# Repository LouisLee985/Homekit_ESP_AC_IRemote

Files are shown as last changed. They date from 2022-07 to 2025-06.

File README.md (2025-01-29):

# Homekit_ESP_AC_IRemote


<p align="center">

</p>

<p align="center">

</p>
<br>

### [WiFiManager](https://github.com/tzapu/WiFiManager?tab=readme-ov-file#how-it-works)
* When your ESP starts up, it sets it up in Station mode and tries to connect to a previously saved Access Point
* if this is unsuccessful (or no previous network saved) it moves the ESP into Access Point mode and spins up a DNS and WebServer (default ip 192.168.4.1)
* using any wifi enabled device with a browser (computer, phone, tablet) connect to the newly created Access Point
* because of the Captive Portal and the DNS server you will either get a 'Join to network' type of popup or get any domain you try to access redirected to the configuration portal
* choose one of the access points scanned, enter password, click save
* ESP will try to connect. If successful, it relinquishes control back to your app. If not, reconnect to AP and reconfigure.
* There are options to change this behavior or manually start the configportal and webportal independantly as well as run them in non blocking mode.
<br>

### HomeKit setup
In your iOS device, open Home App and follow normal steps to [add a new accessory](https://support.apple.com/en-us/104998).

* Homekit Normal Code:
  ```
  985-21-985
  ```

* Homekit QR-Code:
<div align="center">
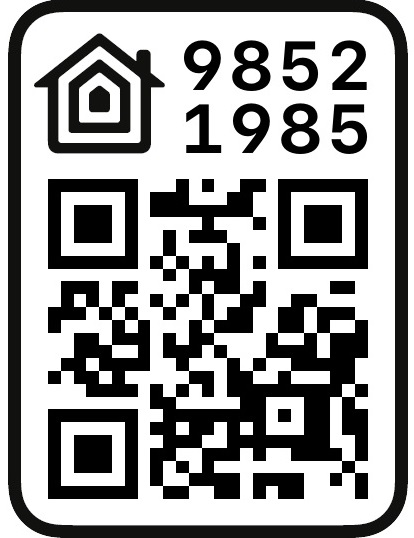
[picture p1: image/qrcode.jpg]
<br>
</div>  　

<br>

   ### Air Conditioning Features

1. Apple HomeKit App Air Conditioning Features: Power on, Power off, Cooling, Heating, ~~Fan speed~~， Current ambient temperature and humidity display. 
<br>Based on [HomeKit Accessory Protocol Specification(Noncommercial Version) Release R2](https://developers.apple.com/homekit/faq)  ，there is a disclaimer stating that *`This accessory has not been certified for use with HomeKit, therefore some features may not be available.`* .
2. If you need to remotely control HomeKit accessories while away from home, please [Set up your HomePod, HomePod mini, Apple TV, or iPad as a home hub](https://support.apple.com/en-us/102557)
3. Infrared Signal Feedback: When a standard air conditioner remote performs actions supported by the Apple HomeKit protocol such as power on, power off, cooling, heating, and ~~fan speed~~, the HomeKit App will synchronously update the status.

<div align="center">
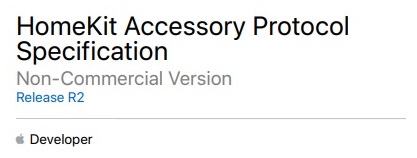
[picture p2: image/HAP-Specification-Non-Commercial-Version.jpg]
<br>
</div>
<br>

### Button IO0

  - Long pressed&ensp;&ensp;5-10 second:&emsp;Set up the infrared protocol.
  - Long pressed&ensp;10-15 second:&emsp;Restore settings.
<br>

# Thanks
* [HomeKit Accessory Protocol Specification(Noncommercial Version) Release R2](https://developers.apple.com/homekit/faq)
* [arduino-sht](https://github.com/Sensirion/arduino-sht) 
* [WiFiManager](https://github.com/tzapu/WiFiManager)
* [IRremoteESP8266](https://github.com/crankyoldgit/IRremoteESP8266) 
* [Arduino-HomeKit-ESP8266](https://github.com/Mixiaoxiao/Arduino-HomeKit-ESP8266) 
* [arduino-button-long-press-short-press](https://arduinogetstarted.com/tutorials/arduino-button-long-press-short-press)
*  https://github.com/openscopeproject/InteractiveHtmlBom

<div align="center">  
 
</div>

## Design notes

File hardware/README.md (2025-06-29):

# AC_IRemote_ESP-01F
* <a href='http://htmlpreview.github.io/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'>InteractiveHtmlBom</a>

<div align="center">
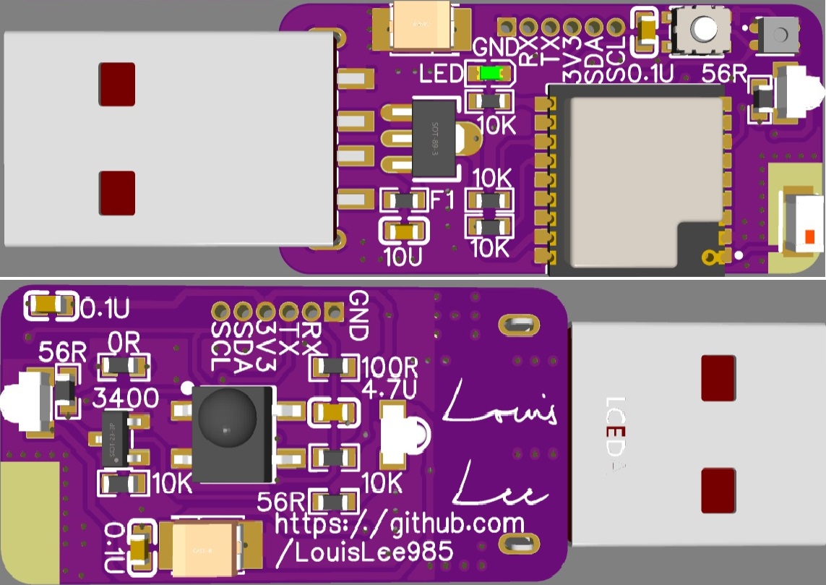
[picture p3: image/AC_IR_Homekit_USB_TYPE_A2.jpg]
AC_IR_Homekit_USB_TYPE_A2
<br>
<br>
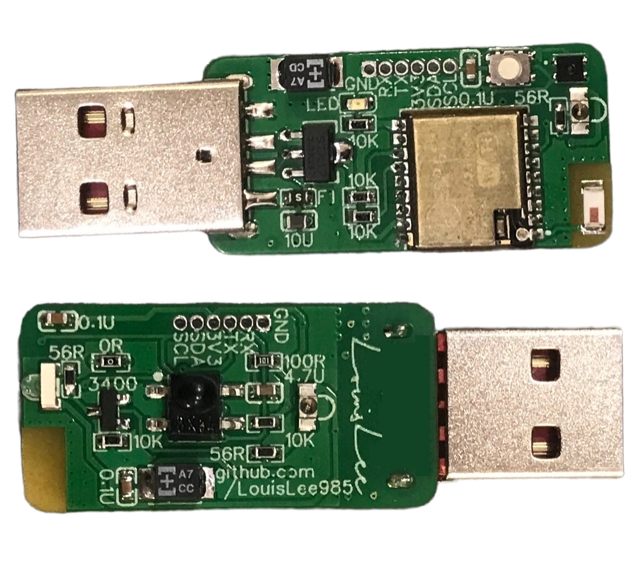
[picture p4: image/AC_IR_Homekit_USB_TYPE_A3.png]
AC_IR_Homekit_USB_TYPE_A3
<br>
<br> 
<br>
<br>
</div>
<br>

* Regarding Temperature and Humidity:
<br>Due to the compactness of the PCB, the temperature and humidity sensor *`SHTC3`*  on the PCB is affected by the heat dissipation of the *`ESP-01F`*  ,resulting in consistently higher temperature readings.
<br>The temperature and humidity sensor and related resistors and capacitors U8,R8,R9,C5，can be left unsoldered, and the temperature and humidity display in the HomeKit App will show 0.

* If accurate temperature and humidity readings are required, do not solder U8,R8,R9,C5， After flashing the firmware, connect an external *`temperature and humidity sensor module`* , keeping it away from heat sources.
<br>SDA,SCL,3V3,GNDare used for connecting an external *`temperature and humidity sensor module`*.
<br>水合：饱和盐水，20-30度，湿度>=70%,密闭小空间>=12小时。

* Supported external SHT *`temperature and humidity sensor modules`*: 　SHTC1，SHTC3，SHTW1，SHTW2，SHT3x-DIS (I2C)，SHT3x-ARP (ratiometric analog voltage output)，SHT85，SHT4x，e.g.
<div align="center">
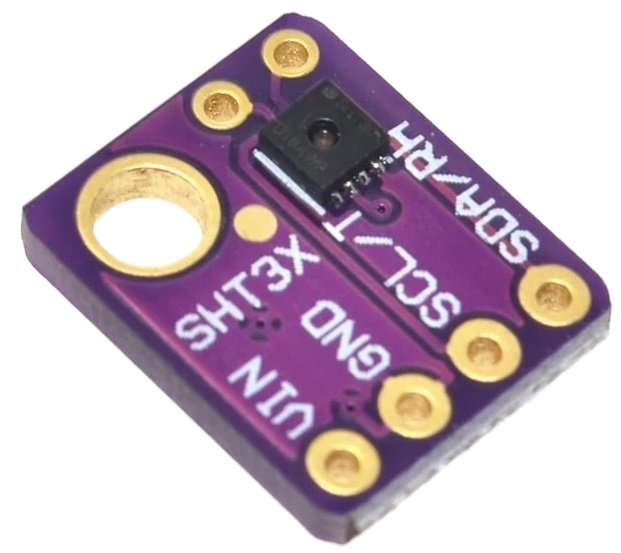
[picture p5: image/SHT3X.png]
<br>
 </div> 

* AC_IRemote_ESP-01F PIN

<div align = "center">

| IR_T(OUT) |IO14|
| :---: |:---: |
|**IR_R(IN)** |**IO12**|
|**LED** |**IO2**|
|**Button**|**IO0** |
|**SDA**|**IO4** |
|**SCL**|**IO5** |
</div>

## [Sparkfun_ir_blaster ](https://github.com/sparkfun/ESP8266_WiFi_IR_Blaster)
* SparkFun WiFi IR Blaster (ESP8266) is supported. 
&emsp;&emsp;
[sparkfun_ir_blaster.bin](https://github.com/LouisLee985/Homekit_ESP_AC_IRemote/releases/download/v1.2.0/Air_Conditioner_Remote_1.2.0-sparkfun_ir_blaster.bin)

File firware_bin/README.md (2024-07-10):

# Homekit_ESP_AC_IRemote

### Installation
<ol>
<li>Connect your device to your FTDI adapter in flash-mode, holding down device button IO0 while connecting or connecting GPIO-0 to GND.
</li>
<li>Use  <a href="https://www.espressif.com.cn/zh-hans/support/download/other-tools">flash_download_tool</a> to flash it in your device.</li>

<br>Homekit_AC_Remote_1.0.0.bin，@0x0
<br>DoNotChgBin is unchecked。
<br>select COM：...，BAUD:115200。
<br>ERASE...
<br>START...
</ol>

<div align="center">
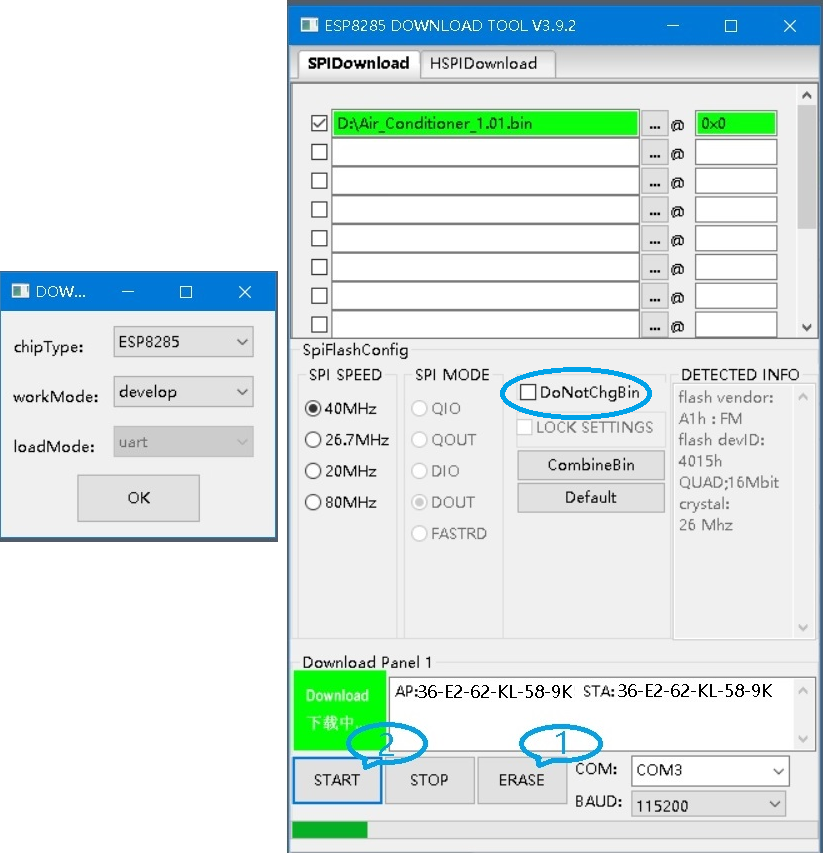
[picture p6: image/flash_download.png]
flash_download
<br>
</div>

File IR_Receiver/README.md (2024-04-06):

## IR receiver Pin  GPIO 12

* Flash to 0x0 of device based on an ESP8266 microcontroller (ESP8266EX and ESP8285 chips), rboot.bin and blank_config.bin is not needed.
* Power off device.
* Connect receiver data pin to GPIO 12 using an IR receiver like <a href="https://www.cytron.io/p-ir-receiver-diode-vs1838b-38khz">VS1838B</a>, <a href="https://www.vishay.com/en/product/82484/">TSMP1138</a> ...
* Power on device using USB adapter.
* Output is transmitted to UART. You can read it using screen command or any other serial reader.
* To get a good capture, put IR transmitter very near of receiver (1cm - 0.4inch).

---
## Data format

* The haa_ir_capture.bin is compiled from <a href="https://github.com/RavenSystem/esp-homekit-devices/releases/tag/HAAIR_1.0.0">HAA IR Capture Tool v1.0</a></h3>

```
Packets: 199
Standard Format
+ 4323 - 4515 +  494 - 1690 +  493 -  585 ... ... ...
HAA RAW Format
JhJkAODFAOAhAODFAODFAOAhATAcATDAATAcATAcATDAATAcATAcATDAATDAATAcATDAATDAATDAATDAATDAATDAATDAATDAATDAATAcATAcATAcATAcATAcATAcATAcATAcATDAATAcATAcATDAATDAATDAATAcATAiANAcATDAATDAATAcATAcATAcATDAATDAATL1JoJ#ATDAASAdASDAATDAATAcATAcASDAATAcATAcASDAATAcASAdASDBASDBASAdASDBASDAASDBASDBASDBASDBASDBASDBASDBASAdASAdASAdASAdASAdASAdASAdASAdASDBARAdASAdASDBARDCARDBARAeARAeARAeARDCARDCARAeARAeARAeARDCARDCAR
```

* IRrecvDumpV2.bin is compiled from <a href="https://github.com/crankyoldgit/IRremoteESP8266">IRremoteESP8266</a>

```
Timestamp : 000470.742,  Library : v2.8.2
Code : 0xA1834AFFFF56 (48 Bits)
Protocol: 34 (MIDEA), Type: 1 (Command), Power: On, Mode: 3 (Heat), Celsius: On, Temp: 27C/80F, On Timer: Off, Off Timer: Off, Fan: 0 (Auto), Sleep: Off, Swing(V): -, Econo: -, Turbo: -, Quiet: Off, Light: -, Clean: -, 8C Heat: -
uint16_t rawData[199] = {4444, 4560,  536, 1714,  538, 618,  ... ... ... };  // MIDEA A1834AFFFF56
uint64_t data = 0xA1834AFFFF56;
```

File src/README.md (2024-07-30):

* 部分代码，部分功能: 制冷，温湿度。如要使用，修改wifi_info.h line13,14中wifi的 ssid password后编译。
* [releases](https://github.com/LouisLee985/Homekit_ESP_AC_IRemote/releases) 实现更多功能。

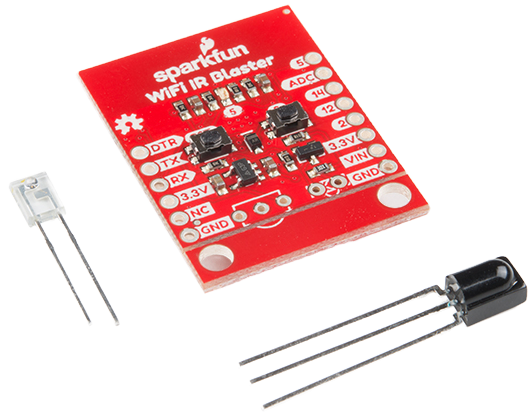
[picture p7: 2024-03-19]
image/SparkFun_WiFi_IR_Blaster_ESP8266.png

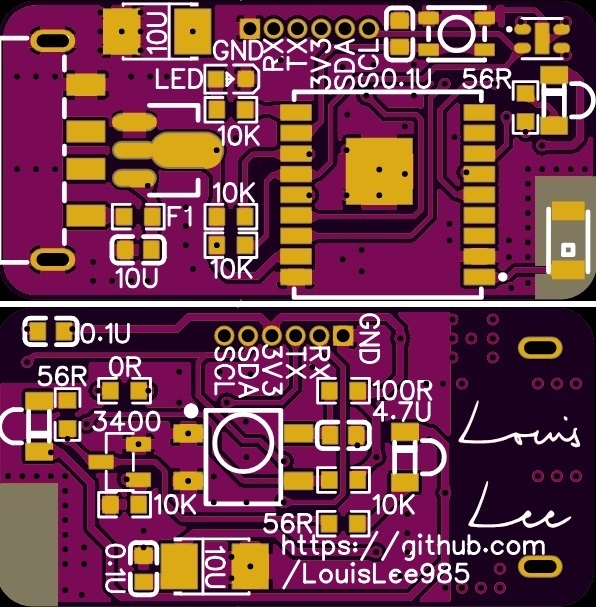
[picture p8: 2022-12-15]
image/AC_IR_Homekit_USB_TYPE_A1.jpg

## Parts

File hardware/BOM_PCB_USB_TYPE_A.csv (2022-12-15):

ID | Name | Designator | Footprint | Quantity | Manufacturer Part | Manufacturer | Supplier | Supplier Part | link
1 | 0R | R6 | R0603 | 1 | ERJ3GEY0R00V | PANASONIC(松下) | LCSC | C122704 | https://www.mouser.in/datasheet/2/447/PYu_RT_1_to_0_01_RoHS_L_11-1669912.pdf
2 | 10U | C1,C8 | CAP-SMD_L3.5-W2.8-R-RD | 2 | 16TQC10M | PANASONIC | LCSC | C147769 | https://atta.szlcsc.com/upload/public/pdf/source/20160107/1457707745471.pdf
3 | 0.1U | C2,C5,C3 | C0603 | 3 | CGA3E2X7R1E104KT0Y0N | TDK | LCSC | C338117 | https://item.szlcsc.com/362304.html
4 | 4.7U | C6 | C0603 | 1 | C1608X5R1C475KTK00E | TDK | LCSC | C342985 | https://item.szlcsc.com/362304.html
5 | IR_R | CGQ1 | SENSOR-SMD_IRM-H638T-TR2-TL | 1 | IRM-H638T/TR2 | EVERLIGHT | LCSC | C91447 | https://item.szlcsc.com/92636.html
6 | 3400 | Q1 | SOT-23-3_L2.9-W1.3-P1.90-LS2.4-BR | 1 | AO3400A | HUASHUO(华朔) | LCSC | C700953 | https://www.diodes.com/assets/Package-Files/SOT23.pdf
7 | 10K | R1,R10,R2,R8,R9 | R0603 | 5 | ERJU3RD1002V | PANASONIC | LCSC | C491175 | https://www.mouser.in/datasheet/2/447/PYu_RT_1_to_0_01_RoHS_L_11-1669912.pdf
8 | 56R | R4,R5,R3 | R0603 | 3 | ERJ3RED56R0V | PANASONIC | LCSC | C416765 | https://www.mouser.in/datasheet/2/447/PYu_RT_1_to_0_01_RoHS_L_11-1669912.pdf
9 | 100R | R13 | R0603 | 1 | ERA3AEB101V | PANASONIC | LCSC | C445624 | https://www.mouser.in/datasheet/2/447/PYu_RT_1_to_0_01_RoHS_L_11-1669912.pdf
10 | IR_T | U4,U5,U3 | LED-SMD_L3.0-W2.7-RD | 3 | IR26-61C/L302/TR8 | EVERLIGHT | LCSC | C181893 | https://atta.szlcsc.com/upload/public/pdf/source/20180207/C181893_15179899213401356555.pdf
11 | ESP-01F-2M-LL | L1 | WIFIM-SMD_ESP-01F-2M-LL | 1 | ESP-01F-2M | Ai-Thinker(安信可) | LCSC | C2764054 | https://item.szlcsc.com/2895541.html
12 | K2-1849SN-A3DW-06_LL | SW2 | SW-SMD_4P-L3.0-W2.8-P1.7-LS3.5 | 1 | K2-1849SN-A3DW-06 | Korean Hroparts Elec | LCSC | C442593 | https://atta.szlcsc.com/upload/public/pdf/source/20191030/C442593_F2569C1D94F849BB65E2EF23C54A3D8B.pdf
13 | 2450AT18A100E | AE1 | ANT-SMD_L3.2-W1.6 | 1 | 2450AT18A100E | Johanson Dielectrics | LCSC | C89334 | https://item.szlcsc.com/97946.html
14 | 10U | C9 | C0603 | 1 | C1608X6S1A106MT000E | TDK | LCSC | C342875 | https://item.szlcsc.com/362304.html
15 | 0603L100SLYR | F1 | R0603 | 1 | 0603L100SLYR | Littelfuse | LCSC | C207017 | https://www.mouser.in/datasheet/2/447/PYu_RT_1_to_0_01_RoHS_L_11-1669912.pdf
16 | 19-21/R6C-FP1Q2L/3T | LED | LED0603-RD | 1 | 19-21/R6C-FP1Q2L/3T | EVERLIGHT | LCSC | C93128 | https://item.szlcsc.com/347874.html
17 | AMS1117 | U2 | SOT-89_L4.5-W2.5-P1.50-LS4.2-BR-WXC | 1 | AMS1117-3.3 | Youtai Semiconductor Co., Ltd. | LCSC | C347256
18 | SHTC3 | U8 | SENSORM-SMD_4P-L2.0-W2.0-P1.00 | 1 | SHTC3 | Sensirion | LCSC | C194656 | https://item.szlcsc.com/237872.html
19 | U-G-08WS-W-01 | USB2 | USB-A-SMD_U-G-08WS-W-01 | 1 | U-G-08WS-W-01 | 韩国韩荣 | LCSC | C840351 | https://atta.szlcsc.com/upload/public/pdf/source/20200918/C840351_DD82F555CFE8A4EC814B17A8169E3B99.pdf

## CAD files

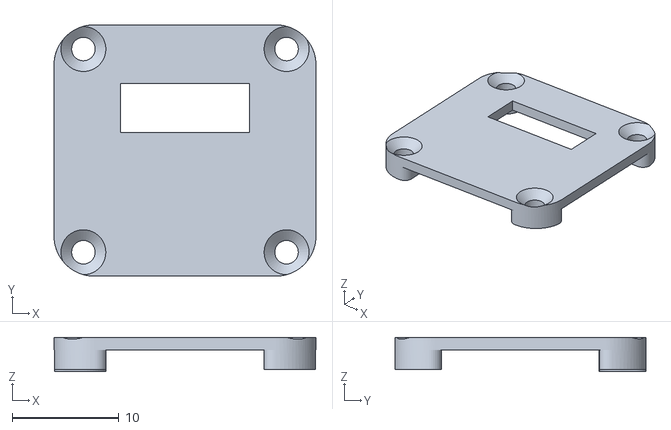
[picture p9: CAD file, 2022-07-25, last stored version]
hardware/AC_IR_Homekit_5V1A_3.0_0402/BASE_15.stl
24.5 x 23.5 x 3.20

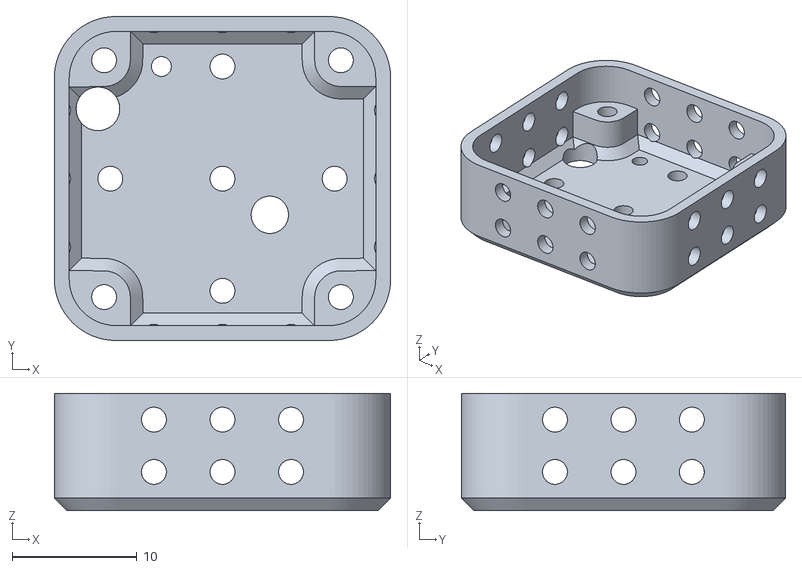
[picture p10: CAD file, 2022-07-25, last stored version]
hardware/AC_IR_Homekit_5V1A_3.0_0402/COVER.stl
27.0 x 26.0 x 9.40

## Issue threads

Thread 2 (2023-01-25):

日立空調能用嗎? RAS-28NK

shengweitw, 2023-01-25:
請問這類空調是否可用?   遙控器型號: RS11T3

shengweitw, 2023-01-25:
請問一下，你的MCU接腳定義與https://github.com/Mixiaoxiao/ESP8266-IR-HOMEKIT相同嗎?

shengweitw, 2023-01-25:
https://github.com/Mixiaoxiao/ESP8266-IR-HOMEKIT

LouisLee985, 2023-01-25:
Yes,but no IO13.

shengweitw, 2023-01-25:
我的遙控器配對，無效，但在上一個版本我可以用RF11T1 remote (HITACHI_AC344)這個設定來控制。這邊該如何設定它使用RF11T1 remote (HITACHI_AC344)這個設定?

LouisLee985, 2023-01-25:
IO0 按钮(IO0接GND) 5秒，遥控器对码。

Closed 2023-07-02.

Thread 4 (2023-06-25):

SparkFun WiFi IR Blaster (ESP8266)

iondarie, 2023-06-25:
Hello,

Is there any way i could get this working on a SparkFun WiFi IR Blaster (ESP8266) board?

IR_LED_RECEIVE = 13
IR_LED_SEND = 4

Thank you,

LouisLee985, 2023-06-30:
IR_SEND_PIN                   14
IR_RECEIVE_PIN                   12

LouisLee985, 2023-06-30:
IR_SEND_PIN =14
IR_RECEIVE_PIN =12

LouisLee985, 2023-07-01:
[ESP8266_WiFi_IR_Blaster](https://github.com/sparkfun/ESP8266_WiFi_IR_Blaster)

iondarie, 2023-07-01:
Thank you!!! I will try asap and come back with the results

iondarie, 2023-07-03:
"Unable to Add Accessory. Accessory is out of compliance"

this is the log if it helps:

```
[20:17:33]>>> [  64541] HomeKit: Got new client: local 192.168.1.96:5556, remote 192.168.1.121:58505
[20:17:33]>>> [  64550] HomeKit: [Client 1073699956] Pair Setup Step 1/3
[20:17:33]>>> [  64632] HomeKit: [Client 1073699956] Pair Setup Step 2/3
[20:17:33]>>> [  64643] HomeKit: Call s_mp_exptmod in integer.c, original winsize 6
[20:17:43]>>> [  74672] HomeKit: Call s_mp_exptmod in integer.c, original winsize 5
[20:17:49]>>> [  79808] HomeKit: [Client 1073699956] Pair Setup Step 3/3
[20:17:49]>>> [  79837] HomeKit: Call ge_double_scalarmult_vartime_lowmem in ge_low_mem.c
[20:17:49]>>> [  80558] HomeKit: Added pairing with 81429B0D-497F-4A9B-BDDB-D96D195999B8
[20:17:49]>>> [  80631] HomeKit: Free saved_preinit_pairing_context
[20:17:49]>>> [  80636] HomeKit: [Client 1073699956] Successfully paired
[20:17:50]>>> [  80880] HomeKit: [Client 1073699956] Disconnected!
[20:17:50]>>> [  80885] HomeKit: [Client 1073699956] Closing client connection
[20:17:50]>>> [  80901] HomeKit: Got new client: local 192.168.1.96:5556, remote 192.168.1.121:58506
[20:17:50]>>> [  80911] HomeKit: [Client 1073683452] Pair Verify Step 1/2
[20:17:50]>>> [  81232] HomeKit: Free heap: 29352
[20:17:50]>>> [  81421] HomeKit: [Client 1073683452] Pair Verify Step 2/2
[20:17:50]>>> [  81428] HomeKit: [Client 1073683452] Found pairing with 81429B0D-497F-4A9B-BDDB-D96D195999B8
[20:17:50]>>> [  81451] HomeKit: Call ge_double_scalarmult_vartime_lowmem in ge_low_mem.c
[20:17:51]>>> [  82182] HomeKit: [Client 1073683452] Verification successful, secure session established
[20:17:51]>>> [  82190] HomeKit: Free heap: 29464
[20:17:51]>>> [  82340] HomeKit: [Client 1073683452] Get Accessories
[20:17:52]>>> [  82857] HomeKit: [Client 1073683452] Disconnected!
[20:17:52]>>> [  82863] HomeKit: [Client 1073683452] Closing client connection
```

LouisLee985, 2023-07-04:
Edited
Retry

iondarie, 2023-07-09:
It works now but it will not send commands to the ac.

LouisLee985, 2023-07-10:
Change IR protocol to yourself :
Long press IO0 KEY 5 second, press ON/OFF key on your original remote.

iondarie, 2023-07-12:
hi, i did change the ir protocol here is my log output

```
Using '/dev/cu.usbserial-0001' as serial port.
Showing logs:
[20:08:19]█      ██      ██        ██████
[20:08:19]            ██  ████      ██  ██  ██  ████        ██    ██
[20:08:19]        ██  ████    ██████████████  ██  ████    ████████████  ██
[20:08:19]                        ██    ██████  ██████  ████      ██
[20:08:19]        ██████████████  ████████████████    ██████  ██  ████████
[20:08:19]        ██          ██    ██████████    ██  ██  ██      ████  ████
[20:08:19]        ██  ██████  ██    ██████    ████    ████████████████
[20:08:19]        ██  ██████  ██  ██    ██  ████████  ██  ██    ████    ████
[20:08:19]        ██  ██████  ██    ██████  ████        ████  ██      ██  ██
[20:08:19]        ██          ██  ██  ████      ██          ██    ██    ████
[20:08:19]        ██████████████  ██      ████          ██████    ████
[20:08:19]
[20:08:19]
[20:08:19]
[20:08:19]
[20:08:38]
[20:08:38] ets Jan  8 2013,rst cause:2, boot mode:(3,1)
[20:08:38]
[20:08:38]load 0x4010f000, len 3460, room 16
[20:08:38]tail 4
[20:08:38]chksum 0xcc
[20:08:38]load 0x3fff20b8, len 40, room 4
[20:08:38]tail 4
[20:08:38]chksum 0xc9
[20:08:38]csum 0xc9
[20:08:38]v000a4ea0
[20:08:38]~ld
[20:08:39]
[20:08:39]LINE 172:  Init  Ac_Protocol: 15
[20:08:39]LINE 176: EEPROM Ac_Protocol: 24
[20:08:39]>>> [    912] HomeKit: Starting server
[20:08:39]>>> [    916] HomeKit: Using existing accessory ID: EC:13:D8:BC:E5:7E
[20:08:39]>>> [    922] HomeKit: Found admin pairing with 81429B0D-497F-4A9B-BDDB-D96D195999B8, disabling pair setup
[20:08:39]>>> [    932] HomeKit: Configuring MDNS
[20:08:39]>>> [    937] HomeKit: MDNS begin: HAC-C0B3DD, IP: 192.168.1.96
[20:08:39]>>> [    946] HomeKit: Init server over
[20:08:39]Setup Code: 985-21-985
[20:08:39]QR Code Generation Time: 23
[20:08:39]QR Code: X-HM://00KVW5QWXAAAA
```

LouisLee985, 2023-07-13:
Ac_Protocol: 24，GREE
Check your hardware

iondarie, 2024-12-31:
@LouisLee985 hello again 😇 , i tested the latest version "Air_Conditioner_Remote_1.2.0-sparkfun_ir_blaster" but i have run into an issue: using the homekit controls disables the lights / display on the my GREE AC unit. Is there something that can be done, a setting i need to do somewhere so my display remains on...

Thank you,

Closed 2023-07-04.

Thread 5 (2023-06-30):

请问IRM和GPIO0引脚定义在哪

addcjy1, 2023-06-30:
想要更改IRM引脚，用以尝试配对涂鸦成品遥控板，以及GPIO0的功能尝试转移至其他IO，可否告知这两个引脚定义位置，我貌似没看到

addcjy1, 2023-06-30:
@LouisLee985

LouisLee985, 2023-06-30:
https://github.com/LouisLee985/Homekit-Air-Conditioner-Remote/issues/4#issuecomment-1614551567

LouisLee985, 2023-06-30:
按键：IO0(D3)，即NodeMCU开发板上的Flash按键

addcjy1, 2023-06-30:
很抱歉，我在src中的各个文件没有看到这几个引脚的定义，只看到了IRCoolixAC ac(14)以及LED_PIN 2，能否再请教一下我修改这几个引脚定义的话应该在何处修改，感谢您耐心解答

LouisLee985, 2023-07-01:
需要改成什么引脚

addcjy1, 2023-07-01:
涂鸦的TYWE3S模块集成的是ESP8266，官方介绍里IO14为IR LED，IO5为IRM，KEY为IO13，这是涂鸦官方的介绍 https://developer.tuya.com/cn/docs/iot/tysw012-round-universal-remote-control?id=K9lnm617oupeb

addcjy1, 2023-07-01:
我在涂鸦的设备刷入了Mixiaoxiao大佬的[ESP8266-IR-HOMEKIT](https://github.com/Mixiaoxiao/ESP8266-IR-HOMEKIT)，并在WEB端修改了IO引脚，使用是正常的，但是因为Mixiaoxiao固件的码库不支持，且该项目咨询了Mixiaoxiao已经停止维护，在issues中看到了您对他人的回答，所以想尝试一下

LouisLee985, 2023-07-02:
Try this:
[Air_Conditioner_Remote_1.6.0-TYSW-012.bin](https://github.com/LouisLee985/Homekit-Air-Conditioner-Remote/blob/main/firware_bin/Air_Conditioner_Remote_1.6.0-TYSW-012.bin)

addcjy1, 2023-07-02:
能否再麻烦您按以下IO生成一份固件，涂鸦的图片不清晰，KEY看着像IO13又像IO15，[Air_Conditioner_Remote_1.6.0-TYSW-012.bin](https://github.com/LouisLee985/Homekit-Air-Conditioner-Remote/blob/main/firware_bin/Air_Conditioner_Remote_1.6.0-TYSW-012.bin)这个版本KEY未生效，尚无法测试红外功能
IO14为IR LED，IO5为IRM，IO15为KEY，IO4为LED

LouisLee985, 2023-07-02:
按下key 5秒后，led闪吗？

addcjy1, 2023-07-02:
不闪，LED只在上电瞬间闪烁，涂鸦官方说明KEY是IO13，看原理图比较模糊看着又像IO15，目前没有万用表可以测试

LouisLee985, 2023-07-02:
重刷试试。
短接IO0和GND 5秒，当KEY使用。

addcjy1, 2023-07-02:
感谢指教，涂鸦焊点脱落，只能等上班有工具了修复再测试，手头Nodemcu只有32S没有8266可测试

jcober, 2023-08-26:
Air_Conditioner_Remote_1.6.0-TYSW-012.bin 刷入后[IO0 按键定义]功能正常 指示灯也正常 homekit可以发现设备 就是添加不了 显示无法添加配件  请问连接代码 是11111111 还是98521985呢

LouisLee985, 2023-08-27:
@jcober 11111111在哪里出现过？

LouisLee985, 2024-04-16:
FLASH is only 1M Bytes.

Closed 2023-07-02.

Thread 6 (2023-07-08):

家庭APP中无法添加

addcjy1, 2023-07-08:
您好，[Air_Conditioner_Remote_1.6.0.bin](https://github.com/LouisLee985/Homekit-Air-Conditioner-Remote/blob/main/firware_bin/Air_Conditioner_Remote_1.6.0.bin)以及[Air_Conditioner_Remote_1.6.0-TYSW-012.bin](https://github.com/LouisLee985/Homekit-Air-Conditioner-Remote/blob/main/firware_bin/Air_Conditioner_Remote_1.6.0-TYSW-012.bin)分别在ESP-12F以及涂鸦设备上运行，家庭APP中均显示“无法添加配件，发生未知错误”
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

LouisLee985, 2023-07-09:
重新下载固件，重新刷机，

Closed 2023-07-11.

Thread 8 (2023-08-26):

设备无法连接homekit，请帮忙看看错误日志

jcober, 2023-08-26:
>>> [ 623044] HomeKit: Got new c
lient: local 192.168.2.112:5556, remote 192.168.2.100:64840
>>>
[ 623053] HomeKit: [Client 1073693604] Pair Setup Step 1/3

>>> [ 629341] HomeKit: [Client 1
073693604] Pair Setup Step 2/3

>>> [ 629352] HomeKit: Call s_mp_exptmod in integer.c, original
winsize 6

>>> [ 639046] HomeKit: Call s_mp
_exptmod in integer.c, original winsize 5

>>> [ 644189] HomeKit: [Client 1
073693604] Pair Setup Step 3/3

>>> [ 644218] HomeKit: Call ge_double_scalarmult_vartime_lowmem in ge_low_mem.c

!!! [ 644939] HomeKit: Failed to
 compact HomeKit storage: sector data read error
!!! [ 644946] HomeKit: Failed to write pairing info to HomeKit storage: max number of pairings
!!! [ 644954] HomeKit: [Client 1073693604] Faile
d to store pairing (code -2)

>>> [ 645007] HomeKit: [Client 1
073693604] Disconnected!
>>> [ 645012] HomeKit: [Client 10736936
04] Closing client connection
>>> [ 645018] HomeKit: Free saved_preinit_pairing_context
>>> [ 645023] HomeKit: [Client 0] Clear
the pairing context

>>> [ 645039] HomeKit: Preiniting pairing context
>>> [ 645043] HomeKit: Using user-specified password: 985-21-985

>>> [ 645063] HomeKit: Call s_mp
_exptmod in integer.c, original winsize 6

>>> [ 651725] HomeKit: Call s_mp
_exptmod in integer.c, original winsize 5

>>> [ 655145] HomeKit: Preinit p
airing context success

>>> [1112863] HomeKit: [Client 1
073691252] Disconnected!
>>> [1112868] HomeKit: [Client 1073691252] Closing client connection

LouisLee985, 2023-08-27:
https://github.com/LouisLee985/Homekit-Air-Conditioner-Remote/issues/5#issuecomment-1616351595

Closed 2023-08-27.

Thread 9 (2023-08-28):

Can I install this over Mixiaoxiao build via web update?

loyukfai, 2023-08-28:
I bought a pre-built unit on Taobao which comes with Mixiaoxiao.

However it doesn't work with my AC (Hitachi RAS-E13CAK)

Also, it has some character limit for WPA key

Can I upgrade to this via web to resolve the above issues?

Cheers.

LouisLee985, 2023-08-29:
1. Connect your device to your FTDI adapter in flash-mode, connecting GPIO-0 to GND or holding down device button while connecting if it uses GPIO-0.
2. Use [flash_download_tool_3.9.5.exe](https://github.com/LouisLee985/Homekit-Air-Conditioner-Remote/blob/main/firware_bin/flash_download_tool_3.9.5_0.zip) to flash it in your device:

- Flash the new firmware with SPI DOUT mode :
- @0x0
- DoNotChgBin is unchecked。
- select COM：...，BAUD:115200。
- ERASE...
- START...

loyukfai, 2023-08-29:
Thanks. So I need to grab a FTDI adapter.

loyukfai, 2023-08-29:
So I must get a FTDI adapter and not use the web update feature (https://camo.githubusercontent.com/8cfe908d3458805fc5bb42540c6d95d97168246aad537b769fed9ae0460dba39/68747470733a2f2f7261772e6769746875622e636f6d2f4d697869616f7869616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 middle pic), right?

LouisLee985, 2023-08-30:
Right.

loyukfai, 2023-08-30:
Thanks. I'll be getting a FTDI adapter and cables to flash it.

https://ibb.co/8jTgGfQ

loyukfai, 2023-09-05:
Hi, I successfully flashed. Do you have any idea how to add it to Home Assistant?

Thanks!

LouisLee985, 2023-09-06:
No idea.

Closed 2023-08-29.

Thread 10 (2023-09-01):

Hitachi RE11T1 Unable to pair

shengweitw, 2023-09-01:
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

I saw your definition, it should be the same as the picture above.

Can Hitachi's remote control be recognized?

The remote control model is RE11T1.

LouisLee985, 2023-09-01:
https://github.com/LouisLee985/Homekit-Air-Conditioner-Remote/issues/2#issuecomment-1403375298

LouisLee985, 2024-04-16:
Now flash v1.3.0, set up protocol in wifisetup,
HITACHI_AC344 is 85.
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

Closed 2023-09-01.

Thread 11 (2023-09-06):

Modify pins for ESP-01M remote

ferbulous, 2023-09-06:
Hello, I have this ir remote

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

How do I change the pin to these?
transmitter - gpio04
receiver - gpio14

LouisLee985, 2023-09-06:
Can't change pin,
Download gerber,make PCB,soldering.

https://github.com/LouisLee985/Homekit-Air-Conditioner-Remote/tree/main/hardware#ac_ir_homekit_usb_type_a

Closed 2023-09-06.

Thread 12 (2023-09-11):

能否不要用遙控器配對?

shengweitw, 2023-09-11:
不知道為何，Hitachi AC433 使用遙控器，它就是不會配對，這情況下，有別的配對方式嗎?  例如網頁配置或者其它的方式?

LouisLee985, 2024-04-17:
https://github.com/LouisLee985/Homekit-Air-Conditioner-Remote/issues/10#issuecomment-2059252716

Closed 2023-09-13.

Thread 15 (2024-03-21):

Trying to get it to work with Mitsubishi AC

ferbulous, 2024-03-21:
Hi, my ac is mitsubishi, before flashing the homekit firmware, I installed tasmota-ir to test sending ir command and it works just fine to control the ac.
I did long press button, led starts blinking, pressed the power button of the ac remote, then led stops blinking.
However it doesn't seem to control my ac just yet.
Here's the log output

```
LINE 171:  Init  Ac_Protocol: 15
                                LINE 175: EEPROM Ac_Protocol: 15
                                                                >>> [   4173] HomeKit: Starting server
                                                                                                      >>> [   4177] HomeKit: Using existing accessory ID: F9:D1:29:17:EA:01
   >>> [   4183] HomeKit: Found admin pairing with 08578a17-fdca-486a-8114-c6f199000590, disabling pair setup
                                                                                                             >>> [   4193] HomeKit: Configuring MDNS
                                                                                                                                                    >>> [   4198] HomeKit: MDNS begin: HAC-6A85C7, IP: 192.168.1.53
                                           >>> [   4207] HomeKit: Init server over
                                                                                  Setup Code: 985-21-985
                                                                                                        QR Code Generation Time: 23
                                                                                                                                   QR Code: X-HM://00KVW5QWXAAAA

                                                                                                                                                                        ██████████████    ██    ████    ████    ██  ██████████████
                                                                  ██          ██  ██    ██████████    ██  ██  ██          ██
                                                                                                                                    ██  ██████  ██  ████████████    ██  ██      ██  ██████  ██
                              ██  ██████  ██    ██████  ██████  ██████    ██  ██████  ██
                                                                                                ██  ██████  ██  ██        ████  ██  ████    ██  ██████  ██
                                                                                                                                                                  ██          ██  ████  ██  ████          ██  ██          ██
                                                            ██████████████  ██  ██  ██  ██  ██  ██  ██  ██████████████
                                                                                                                                              ████    ██  ██    ████████
                        ████  ██    ████    ██        ██  ████████  ██████  ████
                                                                                          ████████            ████    ████    ████  ██    ██████  ██
                                                                                                                                                              ██████████████  ████          ████  ██        ██  ██████
                                                      ██████  ████  ██            ████  ██  ████  ██████      ██
                                                                                                                        ██  ██████████████      ██      ██      ██    ██████  ████
                      ████████    ██  ██████    ██  ██    ██  ████████████
                                                                                      ██████    ██████████  ██    ██████████      ████      ██
                                                                                                                                                          ██    ██  ████████  ██████  ██████  ████  ██      ████
                                                ████    ██████  ██  ████  ████████  ██                ██
                                                                                                                          ██        ████        ██  ██████████  ██████  ████
            ██  ████  ██████  ██      ██      ██      ██        ██████
                                                                                  ██  ████      ██  ██  ██  ████        ██    ██
                                                                                                                                                ██  ████    ██████████████  ██  ████    ████████████  ██
                                                          ██    ██████  ██████  ████      ██
                                                                                                            ██████████████  ████████████████    ██████  ██  ████████
                                                                                                                                                                              ██          ██    ██████████    ██  ██  ██      ████  ████
                                                                        ██  ██████  ██    ██████    ████    ████████████████
                                                                                                                                          ██  ██████  ██  ██    ██  ████████  ██  ██    ████    ████
                                    ██  ██████  ██    ██████  ████        ████  ██      ██  ██
                                                                                                      ██          ██  ██  ████      ██          ██    ██    ████
                                                                                                                                                                        ██████████████  ██      ████          ██████    ████

                                                          >>> [  49958] HomeKit: Got new client: local 192.168.1.53:5556, remote 192.168.1.40:34178
                                                                                                                                                   >>> [  49968] HomeKit: [Client 1073690116] Pair Verify Step 1/2
                                          >>> [  50289] HomeKit: Free heap: 31720
                                                                                 >>> [  50314] HomeKit: [Client 1073690116] Pair Verify Step 2/2
                                                                                                                                                >>> [  50321] HomeKit: [Client 1073690116] Found pairing with 08578a17-fdca-486a-8114-c6f199000590
                                                                          >>> [  50344] HomeKit: Call ge_double_scalarmult_vartime_lowmem in ge_low_mem.c
                                                                                                                                                         >>> [  51074] HomeKit: [Client 1073690116] Verification successful, secure session established
                                                                               >>> [  51083] HomeKit: Free heap: 31832
                                                                                                                      >>> [  51100] HomeKit: [Client 1073690116] Update Characteristics
               >>> [  51123] HomeKit: [Client 1073690116] Get Characteristics
```

LouisLee985, 2024-03-26:
You can retry

Closed 2024-03-28.

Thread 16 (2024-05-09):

Using with Daikin AC (Daikin64 protoocol)

ferbulous, 2024-05-09:
Hi, after a few attempts to learn the Daikin IR remote, I can't seem to control the daikin ac just yet
The Ac protocol listed is 47, is that the correct protocol for daikin64?

```
LINE 171:  Init  Ac_Protocol: 15
LINE 175: EEPROM Ac_Protocol: 47
>>> [   5342] HomeKit: Starting server
>>> [   5346] HomeKit: Using existing accessory ID: 52:71:5C:79:84:99
>>> [   5352] HomeKit: Found admin pairing with df94ef07-43f3-4d71-a73b-5481c5e4b9bf, disabling pair setup
>>> [   5361] HomeKit: Configuring MDNS
>>> [   5367] HomeKit: MDNS begin: HAC-6A85C7, IP: 192.168.2.117
>>> [   5376] HomeKit: Init server over
Setup Code: 985-21-985
QR Code Generation Time: 23
QR Code: X-HM://00KVW5QWXAAAA

        ██████████████    ██    ████    ████    ██  ██████████████
        ██          ██  ██    ██████████    ██  ██  ██          ██
        ██  ██████  ██  ████████████    ██  ██      ██  ██████  ██
        ██  ██████  ██    ██████  ██████  ██████    ██  ██████  ██
        ██  ██████  ██  ██        ████  ██  ████    ██  ██████  ██
        ██          ██  ████  ██  ████          ██  ██          ██
        ██████████████  ██  ██  ██  ██  ██  ██  ██  ██████████████
                        ████    ██  ██    ████████        
        ████  ██    ████    ██        ██  ████████  ██████  ████
        ████████            ████    ████    ████  ██    ██████  ██
          ██████████████  ████          ████  ██        ██  ██████
        ██████  ████  ██            ████  ██  ████  ██████      ██
        ██  ██████████████      ██      ██      ██    ██████  ████
            ████████    ██  ██████    ██  ██    ██  ████████████
          ██████    ██████████  ██    ██████████      ████      ██
            ██    ██  ████████  ██████  ██████  ████  ██      ████
        ████    ██████  ██  ████  ████████  ██                ██
                ██        ████        ██  ██████████  ██████  ████
        ██  ████  ██████  ██      ██      ██      ██        ██████
            ██  ████      ██  ██  ██  ████        ██    ██
        ██  ████    ██████████████  ██  ████    ████████████  ██
                        ██    ██████  ██████  ████      ██
        ██████████████  ████████████████    ██████  ██  ████████
        ██          ██    ██████████    ██  ██  ██      ████  ████
        ██  ██████  ██    ██████    ████    ████████████████
        ██  ██████  ██  ██    ██  ████████  ██  ██    ████    ████
        ██  ██████  ██    ██████  ████        ████  ██      ██  ██
        ██          ██  ██  ████      ██          ██    ██    ████
        ██████████████  ██      ████          ██████    ████

>>> [  20591] HomeKit: Got new client: local 192.168.2.117:5556, remote 192.168.2.199:50712
>>> [  48930] HomeKit: [Client 1073690404] Pair Verify Step 1/2
>>> [  49251] HomeKit: Free heap: 31936
>>> [  49287] HomeKit: [Client 1073690404] Pair Verify Step 2/2
>>> [  49293] HomeKit: [Client 1073690404] Found pairing with df94ef07-43f3-4d71-a73b-5481c5e4b9bf
>>> [  49317] HomeKit: Call ge_double_scalarmult_vartime_lowmem in ge_low_mem.c
>>> [  50047] HomeKit: [Client 1073690404] Verification successful, secure session established
>>> [  50056] HomeKit: Free heap: 32048
>>> [  50083] HomeKit: [Client 1073690404] Update Characteristics
>>> [  65735] HomeKit: [Client 1073690404] Got characteristic 1.10 change event
>>> [  83208] HomeKit: [Client 1073690404] Get Characteristics
>>> [  95742] HomeKit: [Client 1073690404] Got characteristic 1.10 change event
>>> [ 125744] HomeKit: [Client 1073690404] Got characteristic 1.10 change event
>>> [ 143266] HomeKit: [Client 1073690404] Get Characteristics
>>> [ 155748] HomeKit: [Client 1073690404] Got characteristic 1.10 change event
>>> [ 185756] HomeKit: [Client 1073690404] Got characteristic 1.10 change event
```

Closed 2024-05-10.

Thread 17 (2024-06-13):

İr code help me?

kivanc87, 2024-06-13:
Hello, can you help me where and in what format to enter the remote codes, I am interested in your project. Thanks in advance

LouisLee985, 2024-06-14:
Long press Button IO0 5-10 second: Set up the infrared protocol by your original ac remote

Closed 2024-06-14.

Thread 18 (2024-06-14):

Gpio help me

kivanc87, 2024-06-14:
Hello, what are the gpios in the circuit you made? Also, I have a universal product. How can I adapt its GPIOs to your software?

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

LouisLee985, 2024-06-14:
https://templates.blakadder.com/auvisio_S06.html

BK7231N
or
TYWE3S
?

kivanc87, 2024-06-14:
I made the pins and introduced the remote control, but I think the IR codes did not give any commands. Can you help me if I give you the IR raw commands?

LouisLee985, 2024-06-15:
You can test in  IRsendDemo.ino[https://github.com/crankyoldgit/IRremoteESP8266/blob/master/examples/IRsendDemo/IRsendDemo.ino](url)

kivanc87, 2024-06-15:
Can we change the irsend irrecv pin in your software?

Closed 2024-06-15.

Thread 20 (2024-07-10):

RE11T1 日立遙控器無法配對

shengweitw, 2024-07-10:
使用IRrecvDumpV2.bin調適，在介面是可以看到訊號的，如下:
Timestamp : 000050.215,  Library : v2.8.2
Code : 0x7496D4FB (214 Bits)
                            Protocol: -1 (UNKNOWN), uint16_t rawData[427] = {3466, 1598,  512, 1178,  510, 438,  484, 436,  486, 436,  486, 436,  488, 436,  486, 436,  486, 436,  486, 436,  488, 436,  488, 436,  488, 436,  488, 1178,  512, 434,  486, 436,  488, 436,  486, 436,  486, 436,  488, 436,  486, 436,  486, 436,  486, 438,  484, 438,  486, 438,  484, 438,  484, 438,  484, 438,  486, 438,  482, 440,  482, 440,  480, 1186,  510, 436,  482, 1182,  510, 1178,  512, 1178,  508, 1180,  510, 1178,  508, 1180,  508, 440,  452, 1212,  506, 1182,  508, 1182,  508, 1180,  508, 1180,  506, 1182,  508, 1180,  508, 1182,  508, 1182,  508, 438,  482, 442,  480, 444,  480, 442,  480, 442,  480, 442,  482, 442,  480, 442,  482, 442,  482, 440,  484, 1180,  510, 1178,  512, 436,  486, 438,  484, 1180,  510, 1178,  510, 1178,  510, 1180,  508, 438,  484, 440,  484, 1180,  508, 1180,  508, 440,  484, 440,  484, 440,  482, 1182,  508, 440,  484, 440,  482, 1182,  506, 440,  484, 440,  482, 1184,  504, 1184,  504, 442,  480, 1186,  502, 1186,  502, 446,  478, 1186,  500, 1188,  498, 446,  476, 1192,  472, 1218,  470, 474,  474, 448,  454, 1214,  472, 472,  448, 474,  448, 476,  446, 476,  444, 478,  446, 1222,  468, 1220,  466, 476,  446, 1222,  464, 1226,  462, 1226,  462, 480,  442, 482,  442, 1226,  462, 480,  444, 480,  440, 1232,  434, 1272,  416, 506,  418, 1272,  438, 1248,  440, 484,  416, 1274,  414, 1274,  414, 510,  414, 510,  414, 1276,  412, 512,  412, 512,  412, 512,  410, 514,  408, 514,  408, 514,  406, 520,  402, 520,  404, 1284,  404, 1286,  404, 1284,  404, 1286,  402, 1286,  402, 1286,  404, 1286,  402, 1286,  402, 544,  380, 544,  378, 544,  380, 544,  380, 544,  378, 544,  378, 544,  378, 544,  378, 1286,  402, 1286,  402, 1288,  402, 1308,  380, 1310,  378, 1310,  378, 1310,  380, 1308,  380, 544,  378, 546,  378, 544,  380, 544,  378, 546,  378, 544,  378, 544,  378, 544,  378, 1310,  378, 1310,  378, 1310,  378, 1312,  378, 1310,  378, 1310,  378, 1310,  378, 1310,  378, 546,  378, 546,  376, 546,  376, 546,  378, 546,  376, 546,  376, 546,  354, 594,  330, 1334,  354, 1336,  352, 1336,  352, 1360,  328, 1336,  352, 1360,  328, 1360,  328, 1360,  328, 594,  328, 594,  328, 594,  328, 596,  328, 594,  328, 596,  326, 596,  326, 620,  302, 1362,  326, 1362,  326, 1376,  314, 1386,  302, 1388,  302, 1388,  300, 1388,  300, 1388,  300, 1414,  274, 1412,  276, 650,  274, 650,  274, 1416,  254, 694,  222, 1468,  220, 706,  218, 728,  194, 730,  194, 1520,  168, 1572,  88};  // UNKNOWN 7496D4FB

Timestamp : 000051.456,  Library : v2.8.2
Code : 0xAF6BBDC (85 Bits)
                          Protocol: -1 (UNKNOWN), uint16_t rawData[169] = {222, 1442,  248, 1440,  248, 1414,  298, 1388,  300, 1388,  300, 1388,  300, 622,  300, 622,  300, 622,  300, 622,  300, 622,  302, 622,  302, 622,  302, 1362,  326, 1362,  326, 1362,  328, 1362,  326, 1362,  326, 1362,  328, 1360,  328, 1362,  328, 596,  328, 1360,  328, 1362,  328, 596,  326, 596,  328, 596,  328, 596,  326, 596,  326, 596,  326, 596,  326, 596,  326, 1360,  328, 1362,  328, 1360,  328, 1360,  328, 1360,  326, 1362,  328, 596,  326, 596,  328, 594,  328, 596,  326, 596,  328, 596,  328, 596,  326, 596,  326, 1362,  328, 1362,  328, 1360,  328, 1362,  328, 1360,  328, 1360,  328, 1362,  328, 1360,  328, 596,  326, 598,  326, 596,  326, 596,  328, 596,  326, 598,  326, 622,  302, 622,  300, 1364,  326, 1388,  302, 1388,  300, 1388,  300, 1388,  300, 1388,  300, 1388,  300, 1390,  298, 650,  274, 648,  274, 650,  272, 650,  272, 652,  248, 700,  222, 702,  222, 702,  222, 1468,  220, 1494,  194, 1520,  168, 1520,  168, 1548,  134, 1580,  86};  // UNKNOWN AF6BBDC
但，進入遙控器配對時，就是無法正常配對。請問這是為何?

shengweitw, 2024-07-10:
或者可以直接設定成HITACHI_AC344，這個模式就好，我的冷氣全是走這個模式的

LouisLee985, 2024-07-11:
It must be `Protocol: 85 (HITACHI_AC344)`, not `Protocol: -1 (UNKNOWN)`,check your hardware.

shengweitw, 2024-07-11:
IR_T(OUT) | IO14
IR_R(IN) | IO12

這樣接，對嗎?

> It must be `Protocol: 85 (HITACHI_AC344)`, not `Protocol: -1 (UNKNOWN)`,check your hardware. If only set to HITACHI_AC344 in BIN , may be no feedback feature.https://github.com/LouisLee985/Homekit_ESP_AC_IRemote/releases/download/v1.2.0/Air_Conditioner_Remote_1.2.0.085.bin

shengweitw, 2024-07-11:
我用您提供的Air_Conditioner_Remote_1.2.0.085.bin，發出訊號，得到的卻是
Timestamp : 000258.674,  Library : v2.8.2
Code : 0x4EEDB95C (139 Bits)
                            Protocol: -1 (UNKNOWN), uint16_t rawData[277] = {3344, 1698,  426, 1238,  424, 456,  448, 460,  446, 458,  446, 460,  446, 462,  444, 456,  448, 470,  444, 482,  420, 458,  446, 482,  422, 460,  444, 1230,  426, 484,  420, 484,  422, 484,  422, 482,  420, 482,  422, 484,  422, 482,  422, 484,  422, 482,  422, 482,  422, 484,  420, 484,  420, 484,  420, 484,  422, 482,  420, 486,  424, 480,  424, 1228,  424, 482,  422, 1232,  394, 1260,  394, 1238,  416, 1236,  422, 1232,  424, 1230,  450, 482,  424, 1204,  452, 1202,  454, 1200,  454, 1198,  456, 1200,  452, 1202,  452, 1202,  450, 1204,  450, 1204,  448, 456,  446, 458,  446, 458,  446, 458,  442, 462,  440, 462,  442, 464,  442, 464,  440, 466,  438, 486,  414, 1240,  390, 1264,  414, 490,  414, 490,  390, 1264,  390, 1266,  390, 1266,  388, 1266,  386, 518,  386, 518,  386, 1268,  384, 1270,  384, 520,  382, 522,  382, 522,  380, 1276,  376, 528,  374, 530,  376, 1278,  374, 530,  374, 530,  374, 1280,  374, 1280,  374, 530,  374, 1280,  374, 1280,  374, 530,  376, 1278,  374, 1282,  374, 532,  372, 1282,  372, 1282,  372, 532,  372, 554,  348, 1306,  350, 556,  350, 554,  348, 556,  348, 556,  348, 554,  350, 1306,  348, 1306,  348, 556,  348, 1306,  350, 1304,  348, 1306,  350, 556,  348, 556,  326, 578,  324, 1330,  324, 580,  322, 1332,  324, 1332,  324, 580,  324, 1330,  324, 1332,  324, 1352,  302, 606,  298, 1356,  298, 606,  298, 608,  298, 1356,  298, 608,  296, 608,  296, 608,  296, 608,  296, 610,  296, 628,  276, 610,  296, 636,  268, 1386,  254, 1400,  244, 1412,  242, 1412,  242, 1438,  216, 1438,  216, 1464,  188, 1468,  188, 770,  122};  // UNKNOWN 4EEDB95C

VS1838b的接法，是根據您提供的GPIO12，實在想不出來是哪邊做錯了

LouisLee985, 2024-07-11:
Read VS1838b datasheet ,then connect to Nodemcu.
look like:
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

shengweitw, 2024-07-11:
瞭解，我明天試著完成上面的電路圖。另外，我的模組是可以收到AC1的訊號，如下
Timestamp : 001365.802,  Library : v2.8.2
Code : 0xB2AE4D51F061C40000000010D8 (104 Bits)
                                              Protocol: 41 (HITACHI_AC1), Model: 2 (R-LT0541-HTA-B), Power: Off, Power Toggle: On, Mode: 6 (Cool), Temp: 24C, Fan: 1 (Auto), Swing(V) Toggle: Off, Swing(V): Off, Swing(H): Off, Sleep: Off, On Timer: Off, Off Timer: Off
uint16_t rawData[211] = {3372, 3358,  436, 1234,  414, 356,  454, 1234,  416, 1234,  414, 344,  466, 372,  436, 1236,  416, 372,  436, 1236,  414, 374,  436, 1236,  412, 376,  434, 1234,  416, 1236,  414, 1236,  412, 376,  436, 374,  434, 1236,  414, 374,  434, 376,  434, 1234,  416, 1236,  414, 374,  436, 1234,  414, 376,  434, 1236,  414, 374,  434, 1234,  418, 372,  434, 374,  434, 374,  436, 1234,  416, 1234,  416, 1234,  414, 1234,  414, 1236,  414, 376,  434, 374,  434, 374,  434, 374,  434, 376,  434, 1234,  414, 1236,  414, 374,  434, 374,  434, 376,  434, 396,  412, 1236,  414, 1234,  416, 1234,  416, 376,  434, 374,  436, 376,  432, 1236,  414, 396,  412, 378,  432, 376,  434, 378,  430, 398,  412, 396,  412, 376,  434, 396,  412, 398,  412, 396,  412, 396,  412, 396,  412, 398,  412, 396,  414, 396,  412, 396,  412, 398,  412, 398,  410, 398,  414, 396,  412, 398,  386, 424,  386, 424,  410, 398,  414, 396,  410, 400,  408, 402,  406, 404,  380, 430,  380, 430,  380, 430,  382, 428,  384, 424,  410, 398,  412, 396,  414, 394,  416, 392,  416, 1208,  442, 392,  416, 392,  416, 394,  416, 372,  436, 1210,  438, 1212,  436, 374,  432, 1216,  434, 1216,  430, 378,  428, 380,  428, 382,  428};  // HITACHI_AC1
                                  uint8_t state[13] = {0xB2, 0xAE, 0x4D, 0x51, 0xF0, 0x61, 0xC4, 0x00, 0x00, 0x00, 0x00, 0x10, 0xD8};

Closed 2024-07-11.

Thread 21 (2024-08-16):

LG ac ir remote

kivanc87, 2024-08-16:
Hello, I have an LG air conditioner and I could not adapt it to it. I put it into recognition mode and when I press the air conditioner's remote control, it blinks but it does not receive any commands. I would be very grateful if you could help me.

LouisLee985, 2024-08-21:
- Long pressed  5-10 second: Set up the infrared protocol
- Long pressed 10-15 second: Restore settings

kivanc87, 2024-08-21:
I did it but it didn't work. I tried it on a different air conditioner and it works, but I couldn't get it to work on LG. I would be very happy if you help

kivanc87, 2024-08-21:
kivancsenol@hotmail.com

this is my email

kivanc87, 2024-08-26:
I want to customize the air conditioner for myself. How can I make changes to the LG air conditioner codes?

kivanc87, 2024-09-02:
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

I could never recognize the remote control. I put a screenshot.

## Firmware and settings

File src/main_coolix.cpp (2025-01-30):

#include <Arduino.h>
#include <arduino_homekit_server.h>
#include <stdio.h>
#include <SHTSensor.h>
#include "wifi_info.h"

#include <IRsend.h>
#include <ir_Coolix.h>
//#include <ir_Fujitsu.h>

#define LOG_PRINT(fmt, args...) printf(("%s,%s,LINE%d: " fmt "\n"), __FILE__, __func__, __LINE__, ##args)
#define SENSOR_TEMP_OFFSET 0.0
#define SENSOR_HUM_OFFSET 0.0

void my_homekit_setup();
void my_homekit_loop();
void update_status();
void th_sensor_sample();

// IR settings
// https://github.com/crankyoldgit/IRremoteESP8266/blob/d8aee22117b826945724dfb4f1b94d82d68f31f0/src/IRremoteESP8266.h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
IRCoolixAC ac(14); // Set IR_TX be used to sending the IR_LED message
// IRFujitsuAC ac(14);
// IRac ac(14);

// Globals
bool queueCommand = false;
void flipQueueCommand(bool newState)
{
	// LOG_PRINT("Flipping queueCommand to %d\n", newState);
	queueCommand = newState;
}

SHTSensor sht;

void Led_int()
{
	pinMode(LED_PIN, OUTPUT);
	digitalWrite(LED_PIN, LOW);
}


void setup()
{
	Serial.begin(115200, SERIAL_8N1, SERIAL_TX_ONLY);
	// Serial.begin(115200);
	while (!Serial) // Wait for the serial connection to be establised.
		delay(50);
	Led_int();

	wifi_connect();
	
	Wire.begin(4, 5);
	sht.init();	
	sht.setAccuracy(SHTSensor::SHT_ACCURACY_MEDIUM); // only supported by SHT3x
	
	ac.begin();
	
	my_homekit_setup();
	WiFi.setSleepMode(WIFI_LIGHT_SLEEP); // WIFI_NONE_SLEEP、WIFI_LIGHT_SLEEP、WIFI_MODEM_SLEEP
}

void loop()
{
	my_homekit_loop();
	delay(10);

	if (queueCommand)
	{
		Serial.printf("Homekit App send ir...\n");
		ac.send();
		flipQueueCommand(false);
	}
}


extern "C" homekit_server_config_t config;

extern "C" homekit_characteristic_t ac_name;
extern "C" homekit_characteristic_t optional_name;
extern "C" homekit_characteristic_t serial_number;
extern "C" homekit_characteristic_t ac_active;
extern "C" homekit_characteristic_t current_temperature;
extern "C" homekit_characteristic_t current_relative_humidity;
extern "C" homekit_characteristic_t current_heater_cooler_state;
extern "C" homekit_characteristic_t target_heater_cooler_state;
extern "C" homekit_characteristic_t cooling_threshold_temperature;
extern "C" homekit_characteristic_t rotation_speed;
extern "C" homekit_characteristic_t swing_mode;

extern "C" void accessory_init();

// get temperature and humidity from sensor
void th_sensor_sample()
{
	if (sht.readSample())
	{
		float temperature_c = sht.getTemperature() + SENSOR_TEMP_OFFSET;
		float humidity = sht.getHumidity() + SENSOR_HUM_OFFSET;

		// temperature_f=temperature_c*1.8+32;
		// temperature_f=celsiusToFahrenheit(temperature_c);

		if (temperature_c != current_temperature.value.float_value || humidity != current_relative_humidity.value.float_value)
		{
			current_temperature.value = HOMEKIT_FLOAT(temperature_c);
			current_relative_humidity.value = HOMEKIT_FLOAT(humidity);
			homekit_characteristic_notify(&current_temperature, current_temperature.value);
		}
	}
	else
	{
		Serial.print("Error in readSample()\n");
	}
}

void ac_active_setter(const homekit_value_t value)
{
	bool on = value.bool_value;
	ac_active.value.bool_value = on; // sync the value
	on ? ac.on() : ac.off();
	update_status();
}

void target_heater_cooler_state_setter(const homekit_value_t value)
{
	uint8 state = value.uint8_value;
	target_heater_cooler_state.value = HOMEKIT_UINT8(state);
	update_status();
}

void cooling_threshold_temperature_setter(const homekit_value_t value)
{
	float ctemp = value.float_value;
	cooling_threshold_temperature.value = HOMEKIT_FLOAT(ctemp);
	ac.setTemp(ctemp);
	flipQueueCommand(true);
}

void rotation_speed_setter(const homekit_value_t value)
{
	uint8 sp = value.float_value;
	uint8 newsp = (uint8)(sp / 20);
	rotation_speed.value = HOMEKIT_FLOAT(((float)newsp) * 20);
	// coolix Fan: 7 (Fixed),Fan: 4 (Min),Fan: 2 (Med),Fan: 1 (Max),Fan: 5 (Auto)
	switch (newsp)
	{
	case 5:
		ac.setFan(ac.convertFan(stdAc::fanspeed_t::kAuto));
		break;
	case 4:
		ac.setFan(ac.convertFan(stdAc::fanspeed_t::kMax));
		break;
	case 3:
		ac.setFan(ac.convertFan(stdAc::fanspeed_t::kMedium));
		break;
	case 2:
		ac.setFan(4);
		break;
	case 1:
		ac.setFan(7);
		break;
	case 0:
		ac.setFan(7);
		break;
	}
	flipQueueCommand(true);
}

void swing_mode_setter(const homekit_value_t value)
{
	uint8 state = value.uint8_value;
	swing_mode.value = HOMEKIT_UINT8(state);

	state ? ac.setSwing() : ac.setSwing();

	if (ac_active.value.bool_value)
	{
		flipQueueCommand(true);
	}
}

void update_status()
{
	homekit_value_t new_current_state;
	if (ac_active.value.bool_value == false)
	{
		new_current_state = HOMEKIT_UINT8(0);
	}
	else
	{
		new_current_state = HOMEKIT_UINT8(3);
		// kMideaACCool
		ac.setMode(ac.convertMode(stdAc::opmode_t::kCool));
		ac.setTemp(cooling_threshold_temperature.value.float_value);
	}
	if (!homekit_value_equal(&new_current_state, &current_heater_cooler_state.value))
	{
		current_heater_cooler_state.value = new_current_state;
		homekit_characteristic_notify(&current_heater_cooler_state, current_heater_cooler_state.value);
		flipQueueCommand(true);
	}
}

static uint32_t next_heap_millis = 0;
static uint32_t next_th_sensor_sample_millis = 0;

void my_homekit_setup()
{
	ac_active.setter = ac_active_setter;
	target_heater_cooler_state.setter = target_heater_cooler_state_setter;
	cooling_threshold_temperature.setter = cooling_threshold_temperature_setter;
	rotation_speed.setter = rotation_speed_setter;
	swing_mode.setter = swing_mode_setter;
	
	uint8_t mac[6];
	WiFi.macAddress(mac);
	sprintf(ac_name.value.string_value, "HAC-%02X%02X%02X", mac[3], mac[4], mac[5]);
	sprintf(serial_number.value.string_value,"%02X%02X%02X%02X%02X%02X", mac[0], mac[1], mac[2], mac[3], mac[4], mac[5]);
    
	accessory_init();
	arduino_homekit_setup(&config);
}

void my_homekit_loop()
{
	arduino_homekit_loop();
	const uint32_t t = millis();
	if (t > next_th_sensor_sample_millis)
	{
		// sensor sample every 30 seconds
		next_th_sensor_sample_millis = t + 30 * 1000;
		th_sensor_sample();
	}
	if (t > next_heap_millis)
	{
		// show heap info every 5 seconds
		next_heap_millis = t + 15 * 1000;
		INFO("Free heap: %d, HomeKit clients: %d", ESP.getFreeHeap(), arduino_homekit_connected_clients_count());
	}
}
